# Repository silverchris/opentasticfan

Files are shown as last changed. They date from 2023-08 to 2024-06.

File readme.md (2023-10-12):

# OpentasticFan
OpentasticFan is a replacement for the factory control board found in most Fantastic Fans. It should also be possible to upgrade a basic Fantastic Fan that does not have rain sensing or power opening with the addition of a [Fantastic Fan lift motor assembly](https://www.etrailer.com/Accessories-and-Parts/Fantastic-Vent/FVK6010-80.html).

It supports:
- Cover Opening and Closing
- Rain Sensing
- Fan Speed Control 
- OLED Display and Rotary Encoder for local control
- Remote control via [Home Assistant](https://www.home-assistant.io/)

## Hardware

- [SH1106 128x64 i2c OLED Display](https://www.amazon.ca/dp/B085RYPHT2)
- [Rotary Encoder with button](https://www.amazon.ca/WayinTop-Degree-Encoder-Development-Arduino/dp/B07T3672VK/)
- [Opentasticfan PCB](hardware/2.0)
- Optional Heated Capacitive Rain Sensor

## Software
Opentasticfan uses [ESPHome](https://esphome.io). Configuration is located at [config/2.0](config/2.0).

[Example configuration](config/2.0/example.yaml)

## OpentasticFan Installed
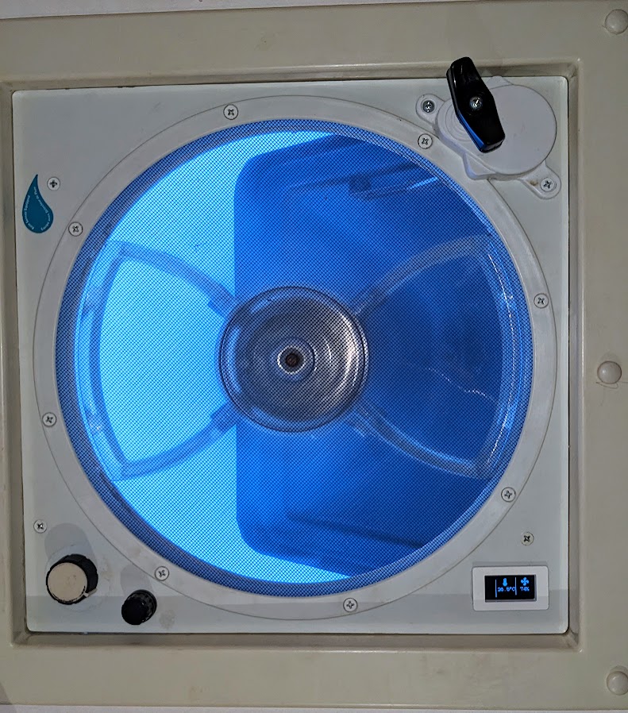
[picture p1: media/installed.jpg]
OpentasticFan Installed


## OpentasticFan wiring
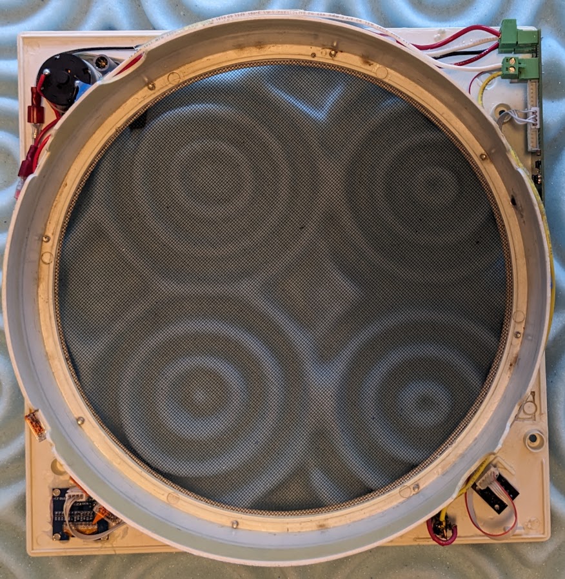
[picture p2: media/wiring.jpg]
OpentasticFan Wiring


## OpentasticFan PCB
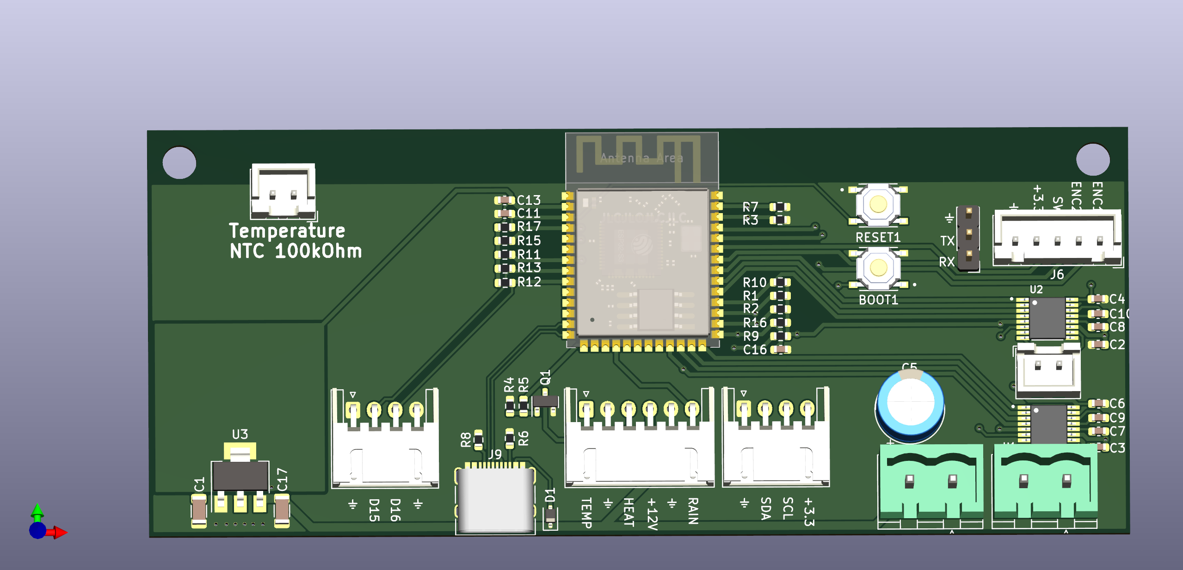
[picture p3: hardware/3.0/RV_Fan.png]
PCB


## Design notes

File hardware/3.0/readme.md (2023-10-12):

# OpentasticFan PCB 3.0

## Updates from 2.0
- Uses ESP32-S3 instead of classic ESP32 (U5)
- USB for programming intergrated (J9, R6, R8, D1)
- Uses DRV8874PWR(U1, U2) for both motor controls. Combined with the better ADC of the ESP32-S3 gives accurate current measurement.
- AMS1117(U3) instead of switch mode regulator for power supply to reduce BOM cost
- Changed from Dallas DS18B20 to NTC thermistor(TH1) for air temperature for both the reduced cost, and due to the flaky support in ESPHome
- Added i2c pullup resistors (R1, R2)

## Assembly Notes
- ESP32-S3-WROOM-1 used, due to poor ADC on the classic ESP32. It is not availible for JLCPCB "Economic PCB Assembly" and will need to be hand soldered.
- Most SMD parts are availible through LCSC/JLCPCB with "Economic PCB Assembly". If having JLCPCB do the SMD assembly, you will need to install/solder C5, J1, J2, J3, J4, J6, J7, J8, U5
- J5 doesn't need to be populated. It's currently unused.
- Install J1, J2, so the screw terminals face out from the PCB with mating connector installed.

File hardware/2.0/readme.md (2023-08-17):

# OpentasticFan PCB

## Assembly Notes
- ESP32-SOLO-1 used on prototypes, for reduced JLCPCB assembly costs.
- All SMD parts are availible through LCSC/JLCPCB with "Economic PCB Assembly". If having JLCPCB do the SMD assembly, you will need to install/solder C5, U5, J1, J2, J3, J4, J6, J10
- If using a NTC thermistor instead of a DS18B20, change R15 to correct value for thermistor
- Recommend using JST XH headers for J3, J4, J6. They fit on this revision, but tightly.
- J5 doesn't need to be populated. It's currently unused.
- Install J1, J2, J10 so the screw terminals face out from the PCB with mating connector installed.

## Future Design changes
- Use ams1117 instead of switch mode regulator to reduce BOM costs/simplify.
- Replace .1" Headers with JST Connectors, for vibration resistance.
- Possibly replace DRV8874 with A4950E. This will likely result in needing to use a op-amp/current sense amplifier to monitor fan current?

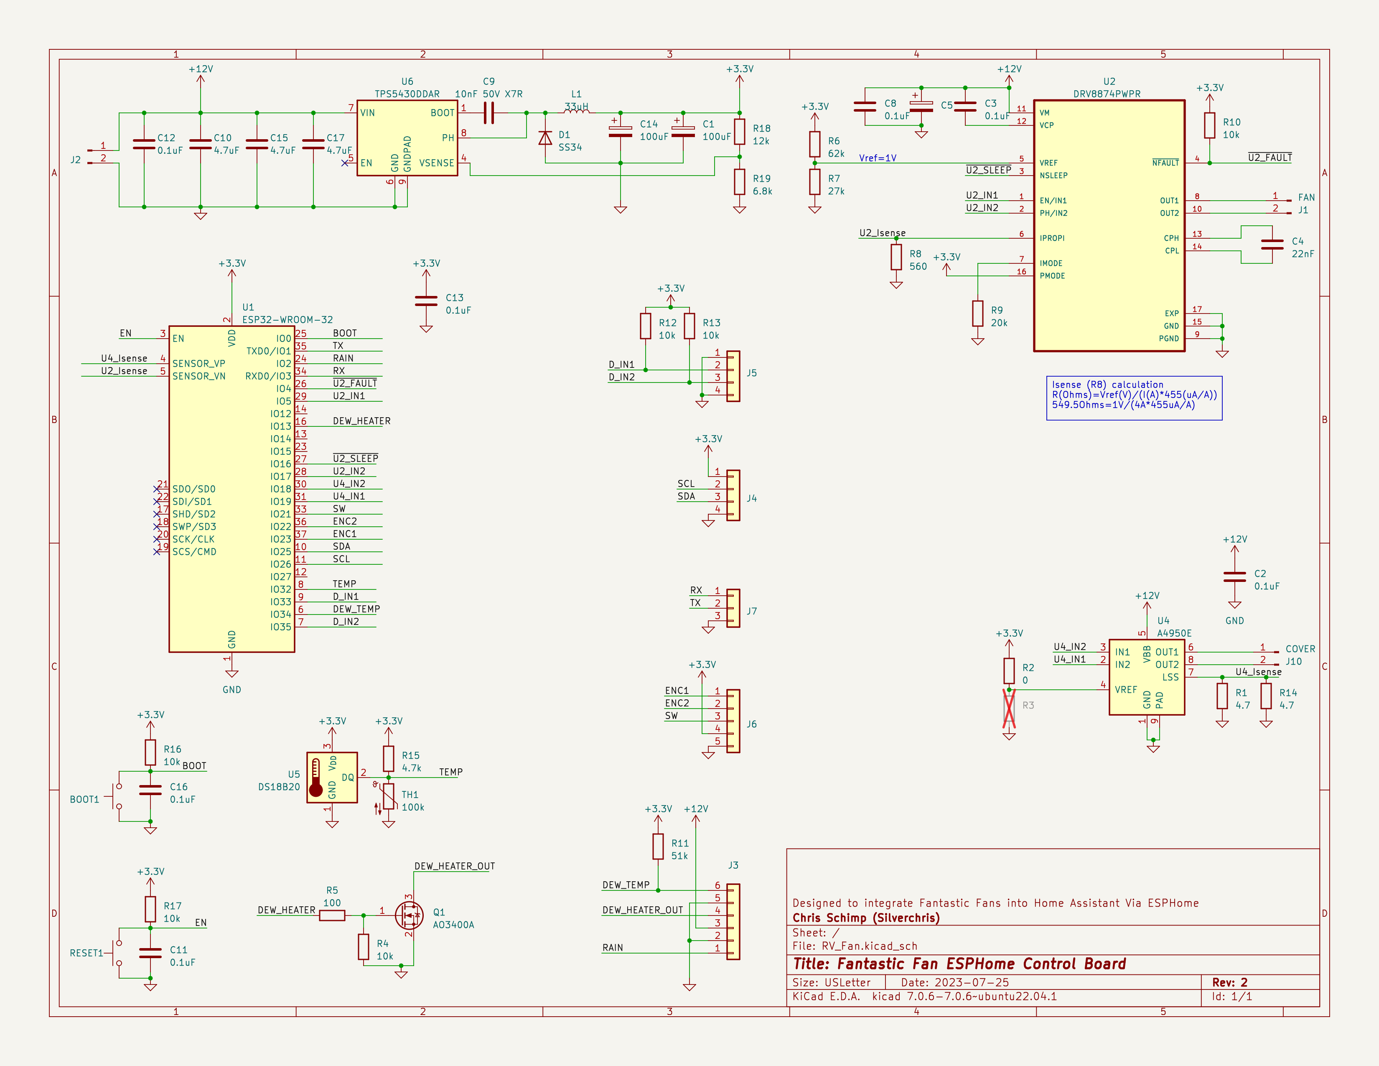
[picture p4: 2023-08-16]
hardware/2.0/schematic.png

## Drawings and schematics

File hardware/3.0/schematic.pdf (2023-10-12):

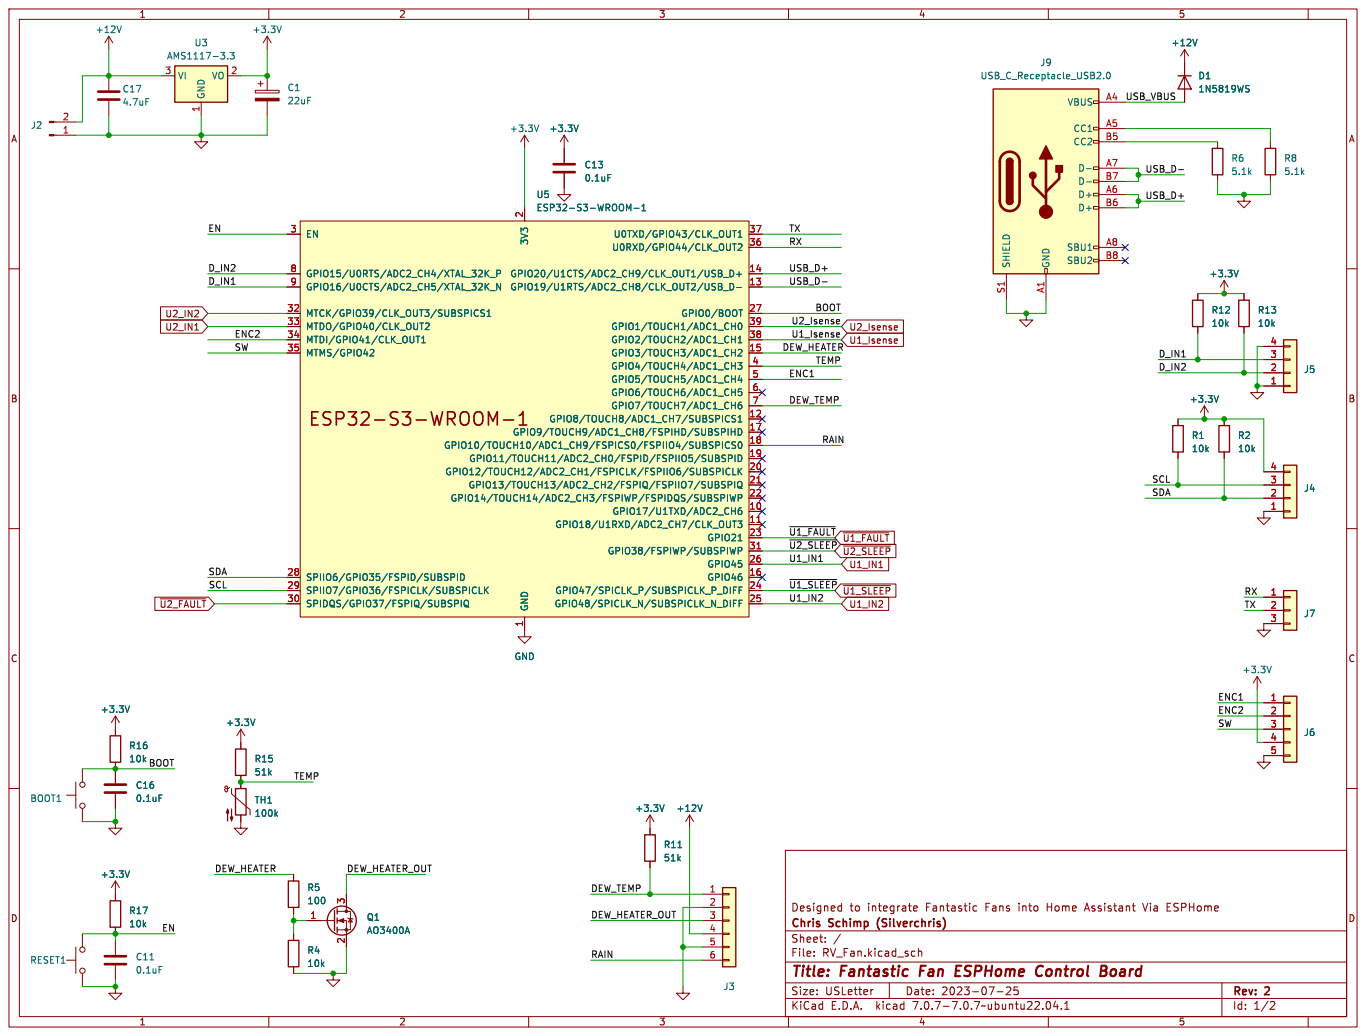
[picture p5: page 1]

2 GPIO12/TOUCH12/ADC2_CH1/FSPICLK/FSPIIO6/SUBSPICLK 20 GPIO13/TOUCH13/ADC2_CH2/FSPIQ/FSPIIO7/SUBSPIQ 21 GPIO14/TOUCH14/ADC2_CH3/FSPIWP/FSPIDQS/SUBSPIWP 22 GPIO21 23 GPIO47/SPICLK_P/SUBSPICLK_P_DIFF 24 GPIO48/SPICLK_N/SUBSPICLK_N_DIFF 25 GPIO45 26 GPIO0/BOOT 27 SPIIO6/GPIO35/FSPID/SUBSPID 28 SPIIO7/GPIO36/FSPICLK/SUBSPICLK 29 EN 3 SPIDQS/GPIO37/FSPIQ/SUBSPIQ 30 GPIO38/FSPIWP/SUBSPIWP 31 MTCK/GPIO39/CLK_OUT3/SUBSPICS1 32 MTDO/GPIO40/CLK_OUT2 33 MTDI/GPIO41/CLK_OUT1 34 MTMS/GPIO42 35 U0RXD/GPIO44/CLK_OUT2 36 U0TXD/GPIO43/CLK_OUT1 37 GPIO2/TOUCH2/ADC1_CH1 38 GPIO1/TOUCH1/ADC1_CH0 39 GPIO4/TOUCH4/ADC1_CH3 4 GPIO5/TOUCH5/ADC1_CH4 5 GPIO6/TOUCH6/ADC1_CH5 6 GPIO7/TOUCH7/ADC1_CH6 7 GPIO15/U0RTS/ADC2_CH4/XTAL_32K_P 8 GPIO16/U0CTS/ADC2_CH5/XTAL_32K_N 9 U5ESP32-S3-WROOM-1

2 GPIO12/TOUCH12/ADC2_CH1/FSPICLK/FSPIIO6/SUBSPICLK 20 GPIO13/TOUCH13/ADC2_CH2/FSPIQ/FSPIIO7/SUBSPIQ 21 GPIO14/TOUCH14/ADC2_CH3/FSPIWP/FSPIDQS/SUBSPIWP 22 GPIO21 23 GPIO47/SPICLK_P/SUBSPICLK_P_DIFF 24 GPIO48/SPICLK_N/SUBSPICLK_N_DIFF 25 GPIO45 26 GPIO0/BOOT 27 SPIIO6/GPIO35/FSPID/SUBSPID 28 SPIIO7/GPIO36/FSPICLK/SUBSPICLK 29 EN 3 SPIDQS/GPIO37/FSPIQ/SUBSPIQ 30 GPIO38/FSPIWP/SUBSPIWP 31 MTCK/GPIO39/CLK_OUT3/SUBSPICS1 32 MTDO/GPIO40/CLK_OUT2 33 MTDI/GPIO41/CLK_OUT1 34 MTMS/GPIO42 35 U0RXD/GPIO44/CLK_OUT2 36 U0TXD/GPIO43/CLK_OUT1 37 GPIO2/TOUCH2/ADC1_CH1 38 GPIO1/TOUCH1/ADC1_CH0 39 GPIO4/TOUCH4/ADC1_CH3 4 GPIO5/TOUCH5/ADC1_CH4 5 GPIO6/TOUCH6/ADC1_CH5 6 GPIO7/TOUCH7/ADC1_CH6 7 GPIO15/U0RTS/ADC2_CH4/XTAL_32K_P 8 GPIO16/U0CTS/ADC2_CH5/XTAL_32K_N 9 +3.3V

1 GPIO17/U1TXD/ADC2_CH6 10 GPIO18/U1RXD/ADC2_CH7/CLK_OUT3 11 GPIO8/TOUCH8/ADC1_CH7/SUBSPICS1 12 GPIO19/U1RTS/ADC2_CH8/CLK_OUT2/USB_D- 13 GPIO20/U1CTS/ADC2_CH9/CLK_OUT1/USB_D+ 14 GPIO3/TOUCH3/ADC1_CH2 15 GPIO46 16 GPIO9/TOUCH9/ADC1_CH8/FSPIHD/SUBSPIHD 17 GPIO10/TOUCH10/ADC1_CH9/FSPICS0/FSPIIO4/SUBSPICS0 18 GPIO11/TOUCH11/ADC2_CH0/FSPID/FSPIIO5/SUBSPID 19 3V3

File: RV_Fan.kicad_sch Sheet: / Chris Schimp (Silverchris)

Id: 1/2 Title: Fantastic Fan ESPHome Control Board

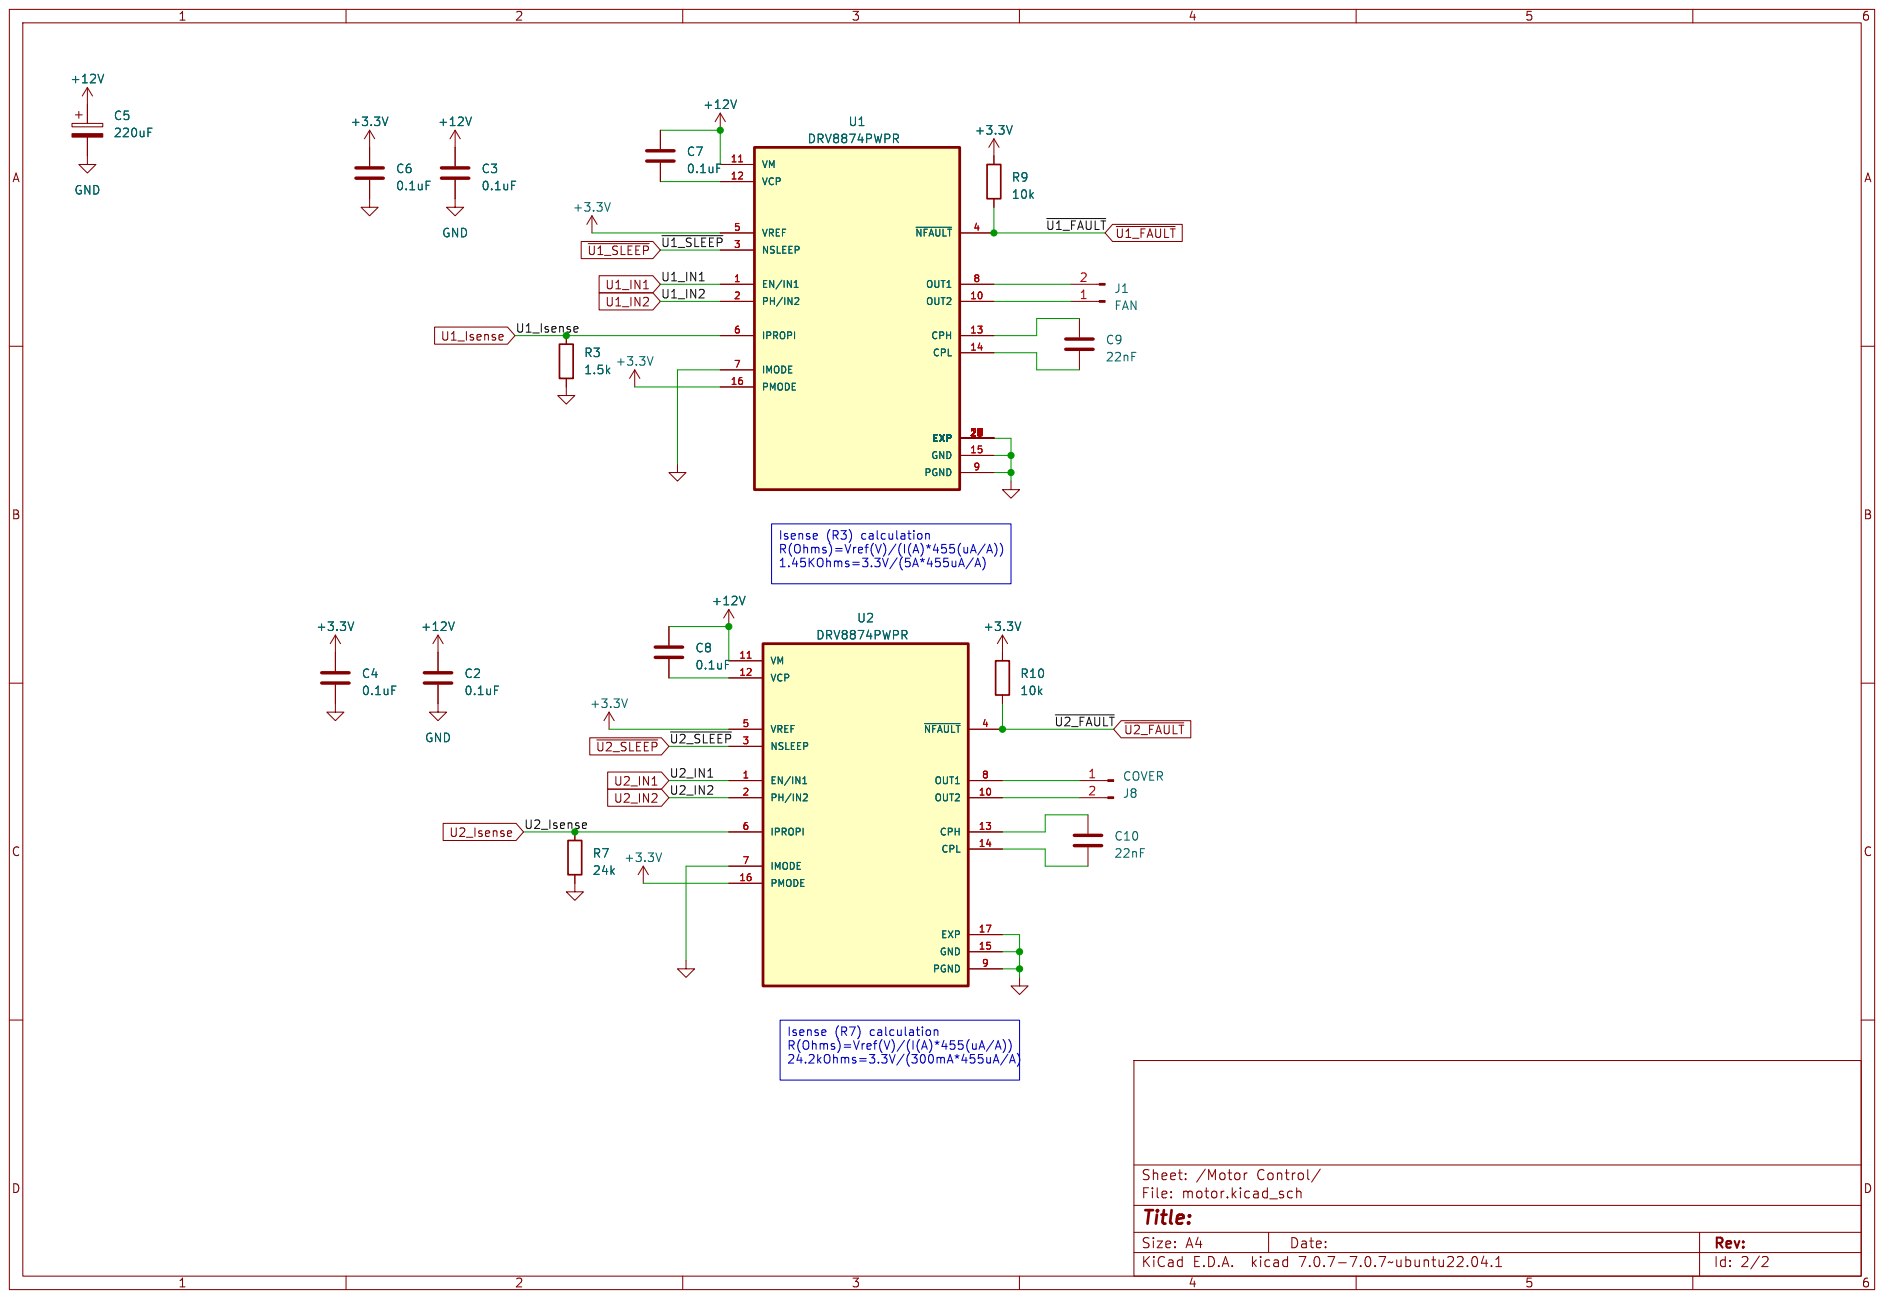
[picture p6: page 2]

Isense (R3) calculation R(Ohms)=Vref(V)/(I(A)*455(uA/A))

Isense (R7) calculation R(Ohms)=Vref(V)/(I(A)*455(uA/A))

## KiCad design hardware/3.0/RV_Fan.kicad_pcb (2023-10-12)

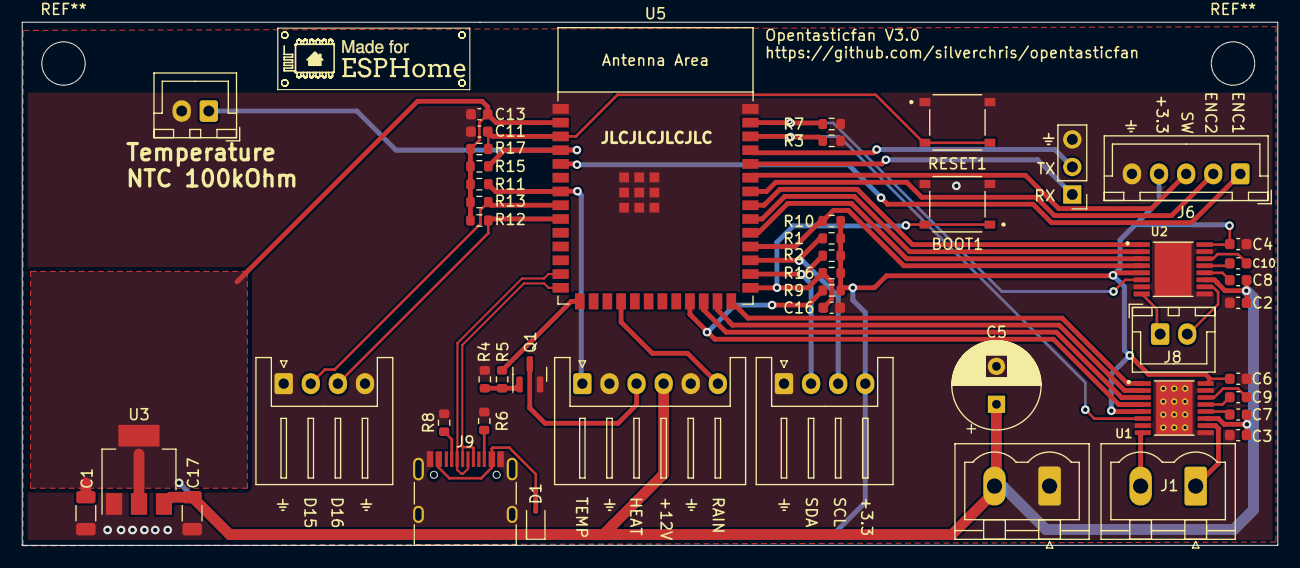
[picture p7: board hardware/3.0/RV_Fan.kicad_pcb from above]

Board: 2 copper layers, 115.8 x 48.3 mm, 48 parts (0 on the bottom side), 45 nets.

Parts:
BOOT1: TS-1187A-B-A-B; button
C1: 22uF; C_1206_3216Metric
C2, C3, C4, C6, C7, C8, C11, C13, C16: 0.1uF; C_0603_1608Metric
C5: 220uF; CP_Radial_D8.0mm_P3.50mm
C9, C10: 22nF; C_0603_1608Metric
C17: 4.7uF; C_1206_3216Metric
D1: 1N5819WS; D_SOD-323
J1: FAN; PhoenixContact_MSTBVA_2,5_2-G-5,08_1x02_P5.08mm_Vertical
J2: PhoenixContact_MSTBVA_2,5_2-G-5,08_1x02_P5.08mm_Vertical
J3: JST_XH_S6B-XH-A_1x06_P2.50mm_Horizontal
J4, J5: JST_XH_S4B-XH-A_1x04_P2.50mm_Horizontal
J6: JST_XH_B5B-XH-A_1x05_P2.50mm_Vertical
J7: PinHeader_1x03_P2.54mm_Vertical
J8: COVER; JST_XH_B2B-XH-A_1x02_P2.50mm_Vertical
J9: USB_C_Receptacle_USB2.0; USB_C_Receptacle_HRO_TYPE-C-31-M-12
Q1: AO3400A; SOT-23
R1, R2, R4, R9, R10, R12, R13, R16, R17: 10k; R_0603_1608Metric
R3: 1.5k; R_0603_1608Metric
R5: 100; R_0603_1608Metric
R6, R8: 5.1k; R_0603_1608Metric
R7: 24k; R_0603_1608Metric
R11, R15: 51k; R_0603_1608Metric
RESET1: TS-1187A-B-A-B; button
TH1: 100k; JST_XH_B2B-XH-A_1x02_P2.50mm_Vertical
U1, U2: DRV8874PWPR; IC_DRV8876PWPT
U3: AMS1117-3.3; SOT-223-3_TabPin2
U5: ESP32-S3-WROOM-1

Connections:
+3.3V: C1.1, C4.1, C6.1, C13.1, J4.4, J6.4, R1.1, R2.1, R9.1, R10.1, R11.1, R12.1, R13.1, R15.1, R16.1, R17.1, U1.5 (VREF), U1.16 (PMODE), U2.5 (VREF), U2.16 (PMODE), U3.2 (VO), U5.2 (3V3)
+12V: C2.1, C3.1, C5.1, C7.1, C8.1, C17.1, D1.1 (K), J2.2, J3.4, U1.11 (VM), U2.11 (VM), U3.3 (VI)
/BOOT: BOOT1.1, C16.1, R16.2, U5.27 (GPIO0/BOOT)
/DEW_HEATER: R5.2, U5.15 (GPIO3/TOUCH3/ADC1_CH2)
/DEW_HEATER_OUT: J3.3, Q1.3 (D)
/DEW_TEMP: J3.1, R11.2, U5.7 (GPIO7/TOUCH7/ADC1_CH6)
/D_IN1: J5.3, R12.2, U5.9 (GPIO16/U0CTS/ADC2_CH5/XTAL_32K_N)
/D_IN2: J5.2, R13.2, U5.8 (GPIO15/U0RTS/ADC2_CH4/XTAL_32K_P)
/EN: C11.1, R17.2, RESET1.2, U5.3 (EN)
/ENC1: J6.1, U5.5 (GPIO5/TOUCH5/ADC1_CH4)
/ENC2: J6.2, U5.34 (MTDI/GPIO41/CLK_OUT1)
/RAIN: J3.6, U5.18 (GPIO10/TOUCH10/ADC1_CH9/FSPICS0/FSPIIO4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)
/RX: J7.1, U5.36 (U0RXD/GPIO44/CLK_OUT2)
/SCL: J4.3, R1.2, U5.29 (SPIIO7/GPIO36/FSPICLK/SUBSPICLK)
/SDA: J4.2, R2.2, U5.28 (SPIIO6/GPIO35/FSPID/SUBSPID)
/SW: J6.3, U5.35 (MTMS/GPIO42)
/TEMP: R15.2, TH1.1, U5.4 (GPIO4/TOUCH4/ADC1_CH3)
/TX: J7.2, U5.37 (U0TXD/GPIO43/CLK_OUT1)
/USB_D+: J9.A6 (D+), J9.B6 (D+), U5.14 (GPIO20/U1CTS/ADC2_CH9/CLK_OUT1/USB_D+)
/USB_D-: J9.A7 (D-), J9.B7 (D-), U5.13 (GPIO19/U1RTS/ADC2_CH8/CLK_OUT2/USB_D-)
/USB_VBUS: D1.2 (A), J9.A4 (VBUS), J9.A9 (VBUS), J9.B4 (VBUS), J9.B9 (VBUS)
GND: BOOT1.2, C1.2, C2.2, C3.2, C4.2, C5.2, C6.2, C11.2, C13.2, C16.2, C17.2, J2.1, J3.2, J3.5, J4.1, J5.1, J5.4, J6.5, J7.3, J9.A1 (GND), J9.A12 (GND), J9.B1 (GND), J9.B12 (GND), J9.S1 (SHIELD), Q1.2 (S), R3.2, R4.2, R6.2, R7.2, R8.2, RESET1.1, TH1.2, U1.7 (IMODE), U1.9 (PGND), U1.15 (GND), U1.17 (EXP), U1.18 (EXP), U1.19 (EXP), U1.20 (EXP), U1.21 (EXP), U1.22 (EXP), U1.23 (EXP), U1.24 (EXP), U1.25 (EXP), U1.26 (EXP), U1.27 (EXP), U1.28 (EXP), U1.29 (EXP), U2.7 (IMODE), U2.9 (PGND), U2.15 (GND), U2.17 (EXP), U3.1 (GND), U5.1 (GND), U5.40 (GND), U5.41 (GND)
unnamed: J1.1, U1.10 (OUT2)
unnamed: J1.2, U1.8 (OUT1)
unnamed: J8.1, U2.8 (OUT1)
unnamed: J8.2, U2.10 (OUT2)
unnamed: J9.A5 (CC1), R8.1
unnamed: J9.B5 (CC2), R6.1
unnamed: Q1.1 (G), R4.1, R5.1
unnamed: C9.1, U1.13 (CPH)
unnamed: C9.2, U1.14 (CPL)
unnamed: C7.2, U1.12 (VCP)
unnamed: C10.1, U2.13 (CPH)
unnamed: C10.2, U2.14 (CPL)
unnamed: C8.2, U2.12 (VCP)
U1_IN1: U1.1 (EN/IN1), U5.26 (GPIO45)
U1_IN2: U1.2 (PH/IN2), U5.25 (GPIO48/SPICLK_N/SUBSPICLK_N_DIFF)
U1_Isense: R3.1, U1.6 (IPROPI), U5.38 (GPIO2/TOUCH2/ADC1_CH1)
U2_IN1: U2.1 (EN/IN1), U5.33 (MTDO/GPIO40/CLK_OUT2)
U2_IN2: U2.2 (PH/IN2), U5.32 (MTCK/GPIO39/CLK_OUT3/SUBSPICS1)
U2_Isense: R7.1, U2.6 (IPROPI), U5.39 (GPIO1/TOUCH1/ADC1_CH0)
~U1_FAULT: R9.2, U1.4 (~NFAULT), U5.23 (GPIO21)
~U1_SLEEP: U1.3 (NSLEEP), U5.24 (GPIO47/SPICLK_P/SUBSPICLK_P_DIFF)
~U2_FAULT: R10.2, U2.4 (~NFAULT), U5.30 (SPIDQS/GPIO37/FSPIQ/SUBSPIQ)
~U2_SLEEP: U2.3 (NSLEEP), U5.31 (GPIO38/FSPIWP/SUBSPIWP)

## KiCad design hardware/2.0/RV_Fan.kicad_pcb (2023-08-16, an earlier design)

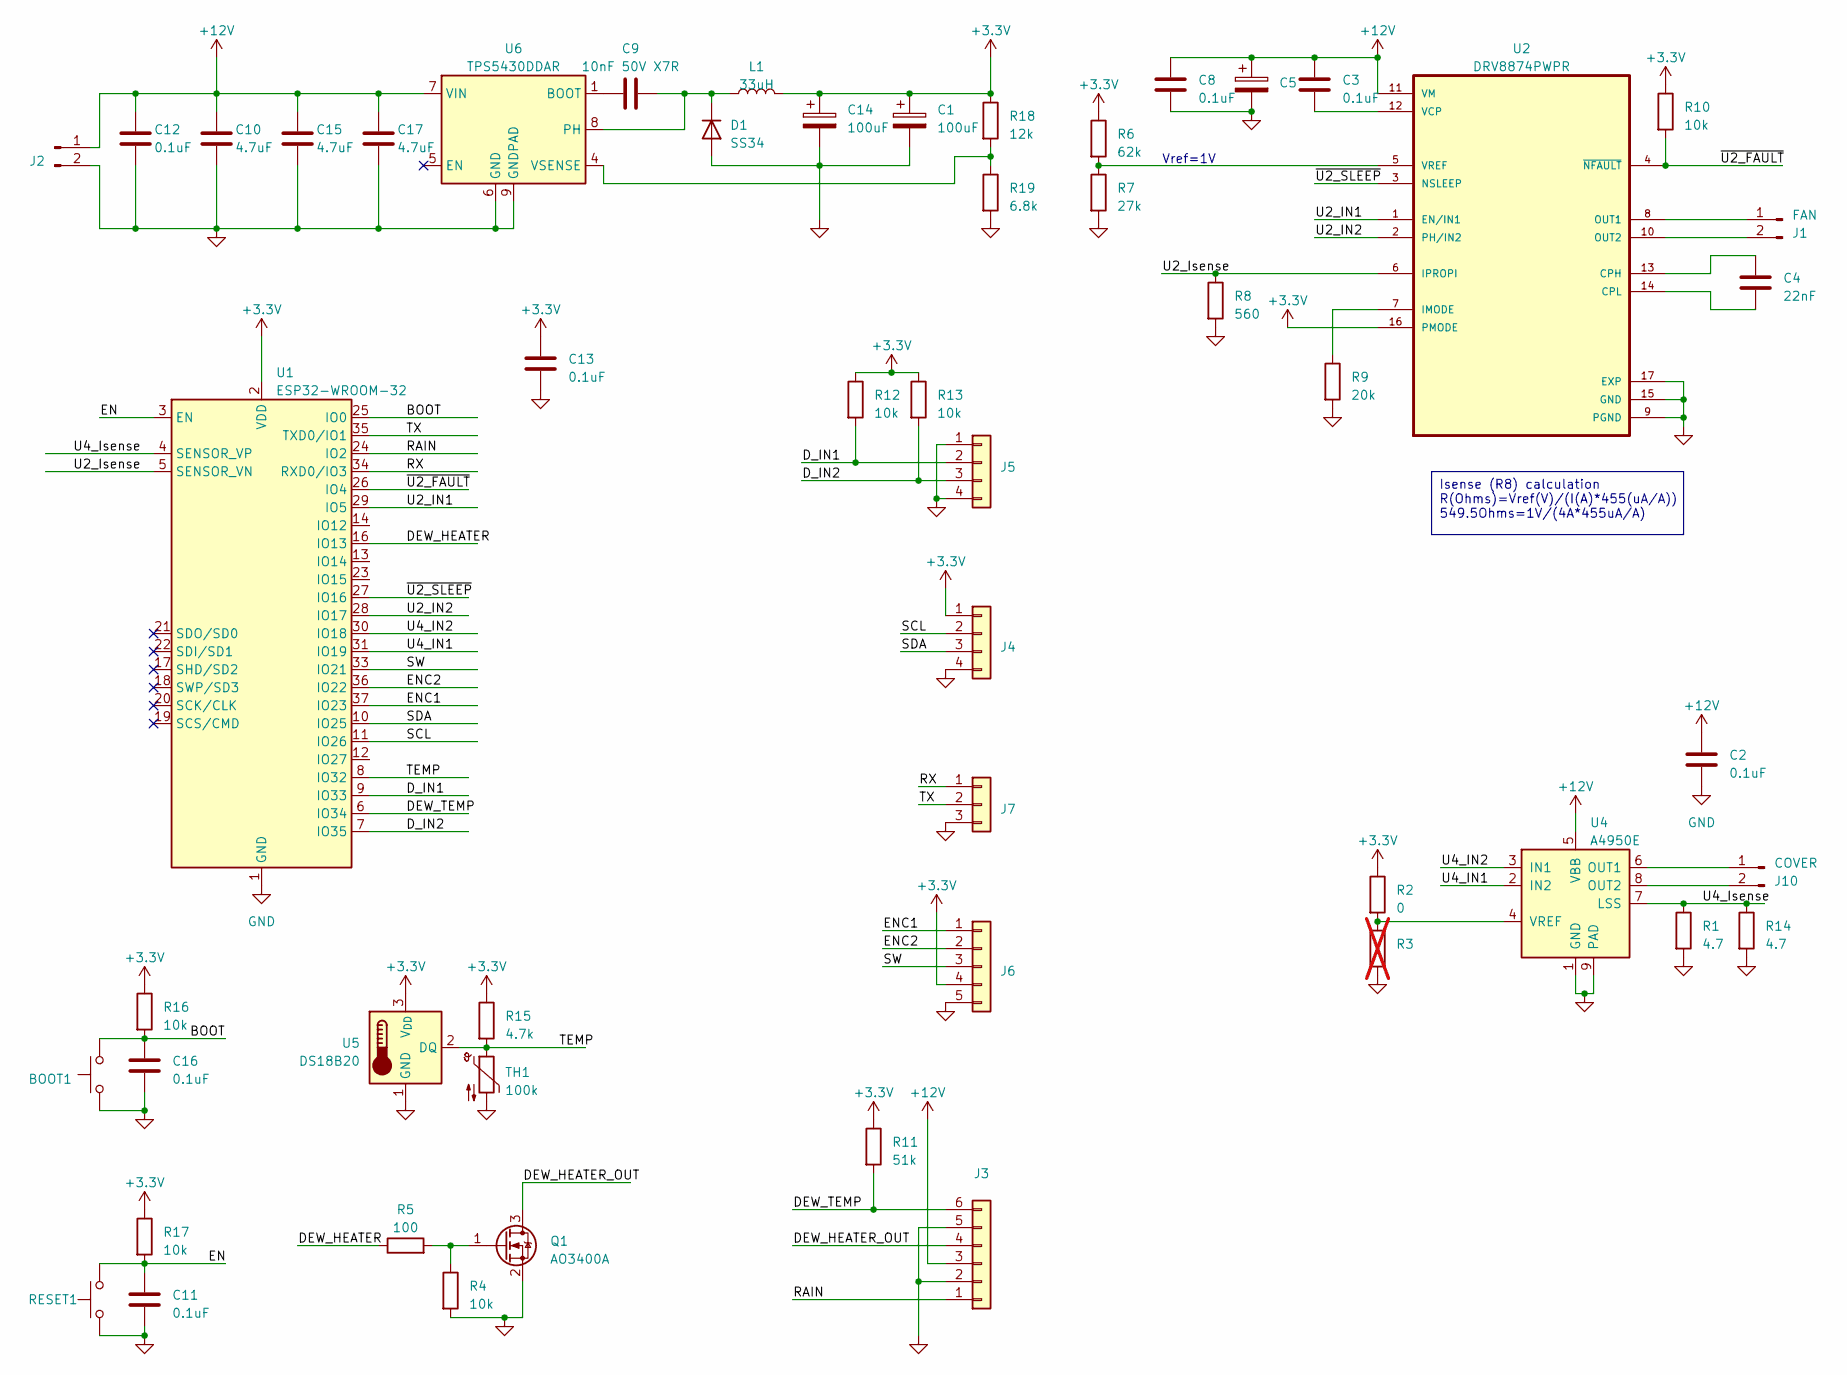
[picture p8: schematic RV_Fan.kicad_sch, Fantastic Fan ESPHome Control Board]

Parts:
BOOT1: TS-1187A-B-A-B; button
C1: 100uF; C_1206_3216Metric
C2, C3, C8, C11, C12, C13, C16: 0.1uF; C_0603_1608Metric
C4: 22nF; C_0603_1608Metric; LCSC Part # C21122
C5: CP_Radial_D8.0mm_P3.50mm
C9: 10nF 50V X7R; C_0603_1608Metric
C10, C15, C17: 4.7uF; C_1206_3216Metric; LCSC Part # C29823
C14: 100uF; C_1206_3216Metric; LCSC Part # C15008
D1: SS34; D_SMA
J1: FAN; PhoenixContact_MSTBVA_2,5_2-G-5,08_1x02_P5.08mm_Vertical
J2: PhoenixContact_MSTBVA_2,5_2-G-5,08_1x02_P5.08mm_Vertical
J3: PinHeader_1x06_P2.54mm_Horizontal
J4, J5: PinHeader_1x04_P2.54mm_Horizontal
J6: PinHeader_1x05_P2.54mm_Vertical
J7: PinHeader_1x03_P2.54mm_Vertical
J10: COVER; PhoenixContact_MSTBVA_2,5_2-G-5,08_1x02_P5.08mm_Vertical
L1: 33uH; 1255AY100MP3; LCSC Part # C1332315
Q1: AO3400A; SOT-23
R1, R14: 4.7; R_0805_2012Metric; LCSC Part # C17675
R2: 0; R_0603_1608Metric
R3: R_0603_1608Metric; not fitted
R4, R10, R12, R13, R16, R17: 10k; R_0603_1608Metric
R5: 100; R_0603_1608Metric
R6: 62k; R_0603_1608Metric
R7: 27k; R_0603_1608Metric
R8: 560; R_0603_1608Metric
R9: 20k; R_0603_1608Metric
R11: 51k; R_0603_1608Metric; LCSC Part # C23196
R15: 4.7k; R_0603_1608Metric
R18: 12k; R_0603_1608Metric
R19: 6.8k; R_0603_1608Metric
RESET1: TS-1187A-B-A-B; button
TH1: 100k; PinHeader_1x02_P2.54mm_Vertical
U1: ESP32-WROOM-32
U2: DRV8874PWPR; IC_DRV8876PWPT; PARTREV E; LCSC Part # C1855818
U4: A4950E; SOIC-8-1EP_3.9x4.9mm_P1.27mm_EP2.41x3.3mm
U5: DS18B20; TO-92_Inline
U6: TPS5430DDAR; TI_SO-PowerPAD-8_ThermalVias

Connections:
+3.3V: C1.1, C13.1, C14.1, J4.1, J6.4, L1.2, R2.1, R6.1, R10.1, R11.1, R12.1, R13.1, R15.1, R16.1, R17.1, R18.1, U1.2 (VDD), U2.16 (PMODE), U5.3 (V_{DD})
+12V: C2.1, C3.1, C5.1, C8.1, C10.1, C12.1, C15.1, C17.1, J2.1, J3.3, U2.11 (VM), U4.5 (VBB), U6.7 (VIN)
/BOOT: BOOT1.1, C16.1, R16.2, U1.25 (IO0)
/DEW_HEATER: R5.1, U1.16 (IO13)
/DEW_HEATER_OUT: J3.4, Q1.3 (D)
/DEW_TEMP: J3.6, R11.2, U1.6 (IO34)
/D_IN1: J5.2, R12.2, U1.9 (IO33)
/D_IN2: J5.3, R13.2, U1.7 (IO35)
/EN: C11.1, R17.2, RESET1.2, U1.3 (EN)
/ENC1: J6.1, U1.37 (IO23)
/ENC2: J6.2, U1.36 (IO22)
/RAIN: J3.1, U1.24 (IO2)
/RX: J7.1, U1.34 (RXD0/IO3)
/SCL: J4.2, U1.11 (IO26)
/SDA: J4.3, U1.10 (IO25)
/SW: J6.3, U1.33 (IO21)
/TEMP: R15.2, TH1.1, U1.8 (IO32), U5.2 (DQ)
/TX: J7.2, U1.35 (TXD0/IO1)
/U2_IN1: U1.29 (IO5), U2.1 (EN/IN1)
/U2_IN2: U1.28 (IO17), U2.2 (PH/IN2)
/U2_Isense: R8.1, U1.5 (SENSOR_VN), U2.6 (IPROPI)
/U4_IN1: U1.31 (IO19), U4.2 (IN2)
/U4_IN2: U1.30 (IO18), U4.3 (IN1)
/U4_Isense: R1.1, R14.1, U1.4 (SENSOR_VP), U4.7 (LSS)
/~U2_FAULT: R10.2, U1.26 (IO4), U2.4 (~NFAULT)
/~U2_SLEEP: U1.27 (IO16), U2.3 (NSLEEP)
GND: BOOT1.2, C1.2, C2.2, C5.2, C8.2, C10.2, C11.2, C12.2, C13.2, C14.2, C15.2, C16.2, C17.2, D1.2 (A), J2.2, J3.2, J3.5, J4.4, J5.1, J5.4, J6.5, J7.3, Q1.2 (S), R1.2, R3.2, R4.2, R7.2, R8.2, R9.2, R14.2, R19.2, RESET1.1, TH1.2, U1.1 (GND), U1.15 (GND), U1.38 (GND), U1.39 (GND), U2.9 (PGND), U2.15 (GND), U2.17 (EXP), U4.1 (GND), U4.9 (PAD), U5.1 (GND), U6.6 (GND), U6.9 (GNDPAD)
unnamed: C9.2, D1.1 (K), L1.1, U6.8 (PH)
unnamed: J1.1, U2.8 (OUT1)
unnamed: J1.2, U2.10 (OUT2)
unnamed: J10.1, U4.6 (OUT1)
unnamed: J10.2, U4.8 (OUT2)
unnamed: Q1.1 (G), R4.1, R5.2
unnamed: C4.1, U2.13 (CPH)
unnamed: C4.2, U2.14 (CPL)
unnamed: R9.1, U2.7 (IMODE)
unnamed: C3.2, U2.12 (VCP)
unnamed: R6.2, R7.1, U2.5 (VREF)
unnamed: R2.2, R3.1, U4.4 (VREF)
unnamed: C9.1, U6.1 (BOOT)
unnamed: R18.2, R19.1, U6.4 (VSENSE)

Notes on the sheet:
Isense (R8) calculation R(Ohms)=Vref(V)/(I(A)*455(uA/A)) 549.5Ohms=1V/(4A*455uA/A)
Vref=1V

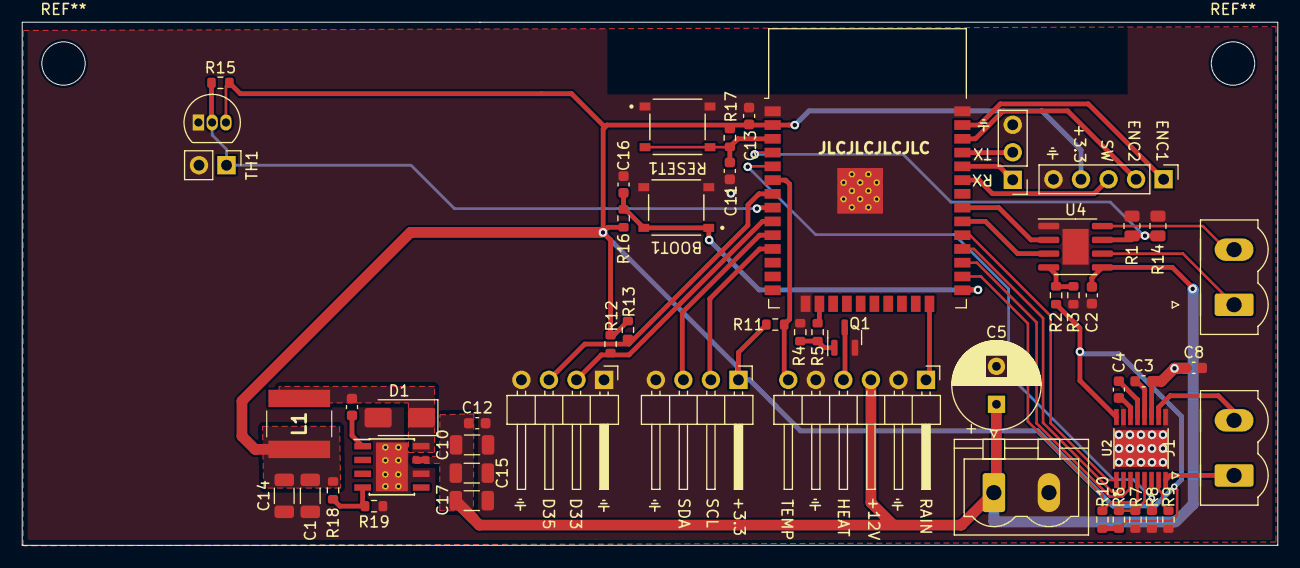
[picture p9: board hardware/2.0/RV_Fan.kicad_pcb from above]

Board: 2 copper layers, 115.8 x 48.3 mm, 53 parts (0 on the bottom side), 41 nets.

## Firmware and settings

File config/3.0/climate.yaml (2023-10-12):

substitutions:
  temperature_sensor: local_temperature
  motor_enable_pin: GPIO47
  motor_forward_pin: GPIO45
  motor_reverse_pin: GPIO48
  motor_error_pin: GPIO21
  motor_current_pin: GPIO2

power_supply:
  - id: "motor_enable"
    pin: ${motor_enable_pin}

output:
  - platform: ledc
    id: motor_forward_pin
    frequency: 32kHz
    pin: ${motor_forward_pin}
    max_power: 0.99
    min_power: 0.40
    zero_means_zero: true
    power_supply: motor_enable
  - platform: ledc
    id: motor_reverse_pin
    pin: ${motor_reverse_pin}
    frequency: 32kHz
    max_power: 0.99
    min_power: 0.40
    zero_means_zero: true
    power_supply: motor_enable
  #Template Output for climate component, so only the enabled component can write to the motor output, and direction
  - platform: template
    id: climate_output
    type: float
    write_action:
      - if:
          condition:
            - lambda: |-
                return id(fan_mode).state == "AUTO";
          then:
            if:
              condition:
                - lambda: |-
                    return id(fan_direction).state == "OUT";
              then:
                - output.set_level:
                    id: motor_forward_pin
                    level: !lambda return state;
              else:
                - output.set_level:
                    id: motor_reverse_pin
                    level: !lambda return state;
  #Template Output for fan component, so only the enabled component can write to the motor output, and direction
  - platform: template
    id: fan_output
    type: float
    write_action:
      - if:
          condition:
            - lambda: |-
                return id(fan_mode).state == "MANUAL";
          then:
            if:
              condition:
                - lambda: |-
                    return id(fan_direction).state == "OUT";
              then:
                - output.set_level:
                    id: motor_forward_pin
                    level: !lambda return state;
              else:
                - output.set_level:
                    id: motor_reverse_pin
                    level: !lambda return state;

fan:
  - platform: speed
    id: my_fan
    name: "Fan"
    output: fan_output
    on_turn_on:
      - climate.control:
          id: fan_climate
          mode: "OFF"

climate:
  - platform: pid
    name: "PID Climate Controller"
    id: fan_climate
    sensor: ${temperature_sensor}
    default_target_temperature: 21°C
    cool_output: climate_output
    control_parameters:
      kp: 1
      ki: 3
      kd: 0.2
    deadband_parameters:
      threshold_high: 0.5
      threshold_low: 0.5

select:
  - platform: template
    name: "Mode"
    id: fan_mode
    optimistic: true
    restore_value: true
    options:
      - MANUAL
      - AUTO
    initial_option: AUTO
    set_action:
      if:
        condition:
          - lambda: |-
              return id(fan_mode).state == "MANUAL";
        then:
          - climate.control:
              id: fan_climate
              mode: "OFF"
        else:
          - fan.turn_off: my_fan
  - platform: template
    name: "Direction"
    id: fan_direction
    optimistic: true
    restore_value: true
    options:
      - IN
      - OUT
    initial_option: OUT
    set_action:
      if:
        condition:
          - lambda: |-
              return id(fan_direction).state == "OUT";
        then:
          - output.set_level:
              id: motor_forward_pin
              level: 0
          - if:
              condition:
                fan.is_on: my_fan
              then:
                - fan.turn_off: my_fan
                - delay: 2s
                - fan.turn_on: my_fan

        else:
          - output.set_level:
              id: motor_reverse_pin
              level: 0
          - if:
              condition:
                fan.is_on: my_fan
              then:
                - fan.turn_off: my_fan
                - delay: 2s
                - fan.turn_on: my_fan

binary_sensor:
  - platform: gpio
    pin:
      number: ${motor_error_pin}
      inverted: true
    name: "Motor Fault"
    filters:
      - delayed_on: 1s

sensor:
  - platform: adc
    pin: ${motor_current_pin}
    update_interval: 1s
    attenuation: 11db
    id: motor_current
    name: Fan Current
    filters:
      - lambda: return (x/1500)/0.000455;
      - quantile:
          window_size: 5
          send_every: 5
          send_first_at: 5
    unit_of_measurement: "A"

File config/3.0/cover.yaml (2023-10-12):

substitutions:
  endstop_current: "120" #Sets the current threshold in mA that turns the endstops on
  cover_open_pin: GPIO40
  cover_close_pin: GPIO39
  cover_current_pin: GPIO1
  cover_enable_pin: GPIO38

output:
  - platform: gpio
    pin: ${cover_close_pin}
    id: cover_close
  - platform: gpio
    pin: ${cover_open_pin}
    id: cover_open
  - platform: gpio
    pin: ${cover_enable_pin}
    id: cover_enable

sensor:
  - platform: adc
    pin: ${cover_current_pin}
    update_interval: .1s
    attenuation: 11db
    id: cover_current
    internal: true
    filters:
      - lambda: return ((x/24000)/0.000455)*1000;
      - quantile:
          window_size: 5
          send_every: 5
          send_first_at: 5
      # - median:
      #     window_size: 5
      #     send_every: 5
      #     send_first_at: 5
    unit_of_measurement: "mA"

binary_sensor:
  - platform: analog_threshold
    name: "Cover Close Endstop"
    sensor_id: cover_current
    threshold: ${endstop_current}
    id: cover_close_endstop
    filters:
      - lambda: if(id(vent_lid).current_operation == CoverOperation::COVER_OPERATION_CLOSING) {return x;} else {return false;}
      - delayed_on: 3s
    internal: true
  - platform: analog_threshold
    name: "Cover Open Endstop"
    sensor_id: cover_current
    threshold: ${endstop_current}
    id: cover_open_endstop
    filters:
      - lambda: if(id(vent_lid).current_operation == CoverOperation::COVER_OPERATION_OPENING) {return x;} else {return false;}
      - delayed_on: 3s
    internal: true

cover:
  - platform: endstop
    name: "Cover"
    id: vent_lid
    open_action:
      - output.turn_on: cover_enable
      - output.turn_on: cover_open
      - select.set:
          id: close_reason
          option: "NONE"
    open_duration: 12s
    open_endstop: cover_open_endstop
    close_action:
      - output.turn_on: cover_enable
      - output.turn_on: cover_close
    close_duration: 12s
    close_endstop: cover_close_endstop
    stop_action:
      - output.turn_off: cover_open
      - output.turn_off: cover_close
      - output.turn_off: cover_enable
    max_duration: 30s

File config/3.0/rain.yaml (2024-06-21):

substitutions:
  rain_sensor_pin: GPIO10
  rain_threshold: "300" #Sets the touch threshold for rain detection. This may need to be tweeked depending on your wiring.
  rain_thermistor_pin: GPIO7
  rain_heater_pin: GPIO3
  rain_measurement_time: 1000us

switch:
  - platform: template
    id: rain_sensor_enable
    name: "Rain Sensor Enable"
    optimistic: true
    restore_mode: RESTORE_DEFAULT_ON

select:
  - platform: template
    name: "Close Reason"
    id: close_reason
    optimistic: true
    options:
      - NONE
      - BOOT
      - RAIN
      - COMMAND
    initial_option: NONE

esp32_touch:
  setup_mode: true
  measurement_duration: ${rain_measurement_time}

binary_sensor:
  - platform: esp32_touch
    id: rain_sensor
    name: "Rain Sensor"
    pin: ${rain_sensor_pin}
    threshold: ${rain_threshold}
    device_class: moisture
    icon: "mdi:weather-pouring"
    filters:
      - delayed_on_off: 5s
    on_press:
      then:
        - if:
            condition:
              switch.is_on: rain_sensor_enable
            then:
              - cover.close: vent_lid
              - logger.log:
                  format: "Cover Closing due to Rain"
                  level: INFO
              - select.set:
                  id: close_reason
                  option: "RAIN"

sensor:
  - platform: resistance
    sensor: rain_thermistor_voltage
    configuration: DOWNSTREAM
    resistor: 51kOhm
    id: rain_thermistor_resistance
    # reference_voltage: 3.12752V
    internal: true
  - platform: adc
    id: rain_thermistor_voltage
    pin: ${rain_thermistor_pin}
    update_interval: 1s
    attenuation: auto
    internal: true
    filters:
      - median:
          window_size: 10
          send_every: 10
          send_first_at: 10
  - platform: ntc
    sensor: rain_thermistor_resistance
    calibration:
      b_constant: 4160
      reference_temperature: 25°C
      reference_resistance: 100kOhm
    name: NTC Temperature
    id: rain_heater_temperature
    internal: true

output:
  - platform: ledc
    frequency: 60hz
    id: rain_heater_output
    pin:
      number: ${rain_heater_pin}
      drive_strength: 40mA
      mode:
        output: true

climate:
  - platform: pid
    name: "Dew Heater"
    id: dew_heater
    sensor: rain_heater_temperature
    default_target_temperature: 40C
    heat_output: rain_heater_output
    control_parameters:
      kp: 1
      ki: 3
      kd: 0.2
#     deadband_parameters:
#       threshold_high: 0.5
#       threshold_low: 0.5

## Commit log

2023-08-16 Added hardware
    [RV_Fan.kicad_pcb, RV_Fan.kicad_sch]
2023-10-12 Add version 3.0
    [RV_Fan.kicad_pcb, RV_Fan.kicad_sch, motor.kicad_sch]
2024-06-20 Enable sensor heater
2024-06-21 Increase rain sensor heater temperature
